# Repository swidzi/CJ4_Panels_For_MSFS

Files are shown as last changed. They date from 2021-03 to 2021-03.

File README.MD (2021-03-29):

# CJ4 Panels

CJ4 Panels are designed to enable an avgeek to build their own Control Panels for [CJ4 Working Tilte Mod](https://github.com/Working-Title-MSFS-Mods/fspackages) for MS Flight Simulator 2020.
Those consist of:

* Eagle files for PCBs (orderable or to be made on a CNC-mill)
* List of electronic components
* STL files for 3d printing
* Inkscape SVG files for laser engraving
* Arduino firmware
* FSUIPC Configuration

Those additionally use certain components from [FlightSimMaker](https://www.thingiverse.com/flightsimmaker/designs) excelent G1000 project - namely [push button switches](https://www.thingiverse.com/thing:4019943) and [Dual Concentric Rotary Encoders](https://www.thingiverse.com/thing:4373531).

## Folder layout

Each panel and component has its own folder. Inside that folder you will find relevant files sorted by type - Eagle, STL etc.
If a certain component requires extra information it will have its own README.MD file.

## Available Panels:

### Primary Flight Display / Display Control Panel

Using a single Arduino/Sparkfun Pro Micro it presents itself to MSFS as a 26 button joystick.

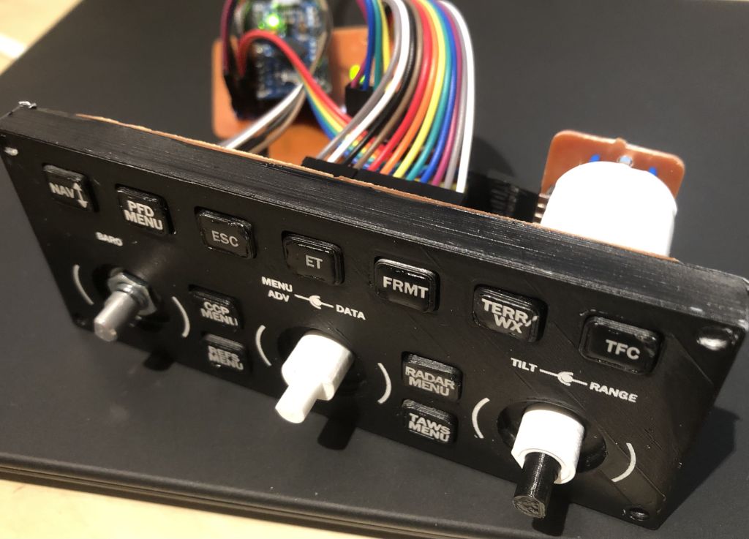
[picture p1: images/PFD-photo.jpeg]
Photo of PFD controller
 <span style="display:block;text-align:center"></span>

## Coming Soon:

### Autopilot / Flight Guindance Panel

Using a single Arduino/Sparkfun Pro Micro it presents itself to MSFS as a 29 button joystick.

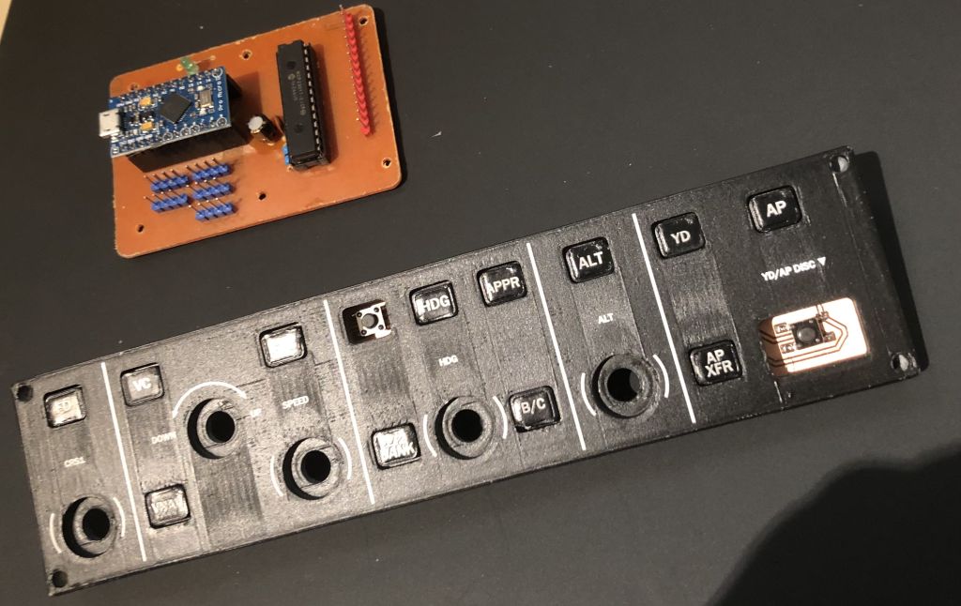
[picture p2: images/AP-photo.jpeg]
Photo of PFD controller
 <span style="display:block;text-align:center"></span>

### Flight Management System (Computer) / Multi-Function Control and Display Unit

Using a single Arudino/Sparkfun Pro Micro and the MMJoy2 interface it presents itself as a 96+ button joystick.

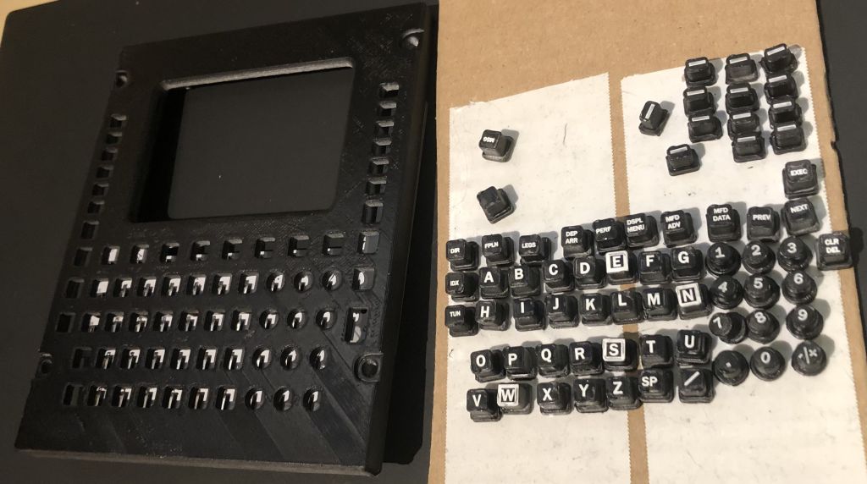
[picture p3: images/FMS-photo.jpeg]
Photo of PFD controller
 <span style="display:block;text-align:center"></span>

### Multi Function Display / Cursor Control Panel

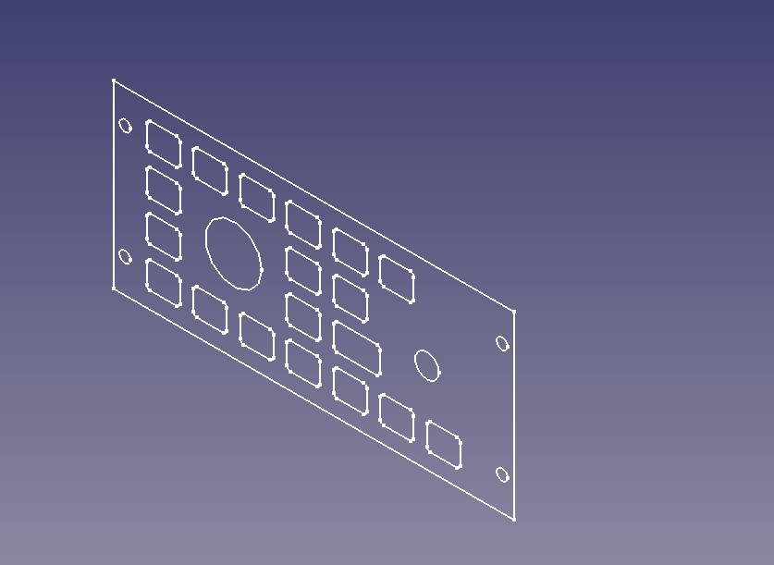
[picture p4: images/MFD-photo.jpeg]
Photo of PFD controller
 <span style="display:block;text-align:center"></span>

## Requirements

* MS Flight Simulator *(I tested it on Steam version)*
* FSUIPC v7 paid version - [link](https://secure.simmarket.com/john-dowson-fsuipc7-for-msfs.phtml)
* MobiFlight WASM module - [link](https://www.mobiflight.com/en/index.html)
* Arduino IDE v1.8.5 or higher - [link](https://www.arduino.cc/)
* Libraries:
	* [Common Bus Encoders](https://github.com/j-bellavance/CommonBusEncoders)
	* Joystick library - available via Manage Libraries in Arduino IDE
	* Adafruit MCP230177 library - available via Manage Libraries in Arduino IDE
* Arduino Pro Micro (based on Atmega32u4) *This is very important! Other AVR chips WILL **NOT** work*

## Building the physical part of the panels

### 3d Printing

Coming soon...

### Laser engraving

Coming soon...

### Making PCBs

Coming soon...

## Installation

#### Installing the software
1. If you have not done so, purchase and install FSUIPC v7
2. Download and install MobiFlight. You do not need to actually be running this software - you just need it's WASM module. Install it in accordance to MobiFlight instructions.
3. Download and install Arduino IDE
* Install required libraries
* If you are using the SparkFun Pro Micro or its clone - Install the proper AVR boards definitions to Arduino Board Manager \([tutorial](https://learn.sparkfun.com/tutorials/installing-arduino-ide/board-add-ons-with-arduino-board-manager)\)

#### Setting up the software:

FSUIPC:
* Copy files from FSUIPC_Configuration folder to your FSUIPC installation folder
* Edit FSUIPC.ini file and modify two lines:
```
[General]
UseProfiles=Files
```
AND
```
[Buttons]
PollInterval=10
```
It is possible that your Arduino Pro Micro joystick will register at a different letter. If that happens you can either:
* Edit the FSUIPC.ini file and change letter assignments in section \[JoyNames\], or
* Edit the Profile files and change letter assignments for each control: For example if you change from Joystick D to F you need to change every occurrence of **PD** to **PF**

#### MS Flight Simulator Setup

At current stage of simulator development no setup is necessary. It is all handled by FSUIPC & MobiFlight combination.

## Usage

Just use like would any joystick controller!

## Contributing

If you find a bug or have a question, feel free to message me on github or to open an Issue.

## Acknowledgments

Many thanks to wonderful people at FlightSimMaker group discord server as well as to all authors who have provided libraries and freeware software available for flightsimmers worldwide

## Questions / Contact

Just drop me an email at swidzi@gmail.com

### License
[GNU GPLv3](https://choosealicense.com/licenses/gpl-3.0/)

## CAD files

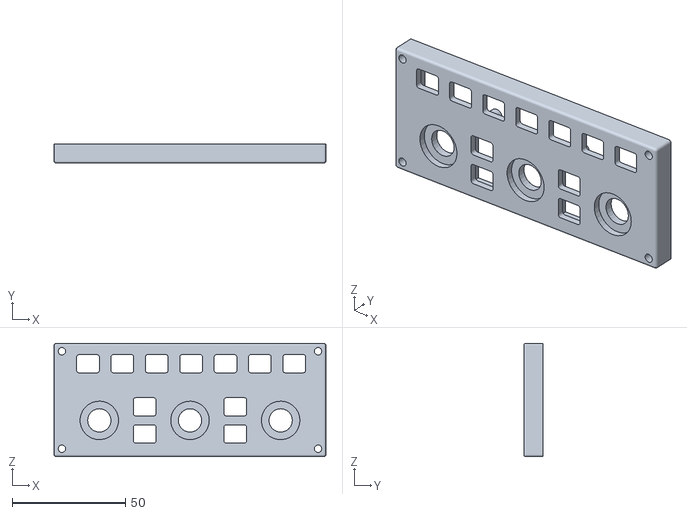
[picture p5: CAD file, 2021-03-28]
PFD/STL/PFD-DCP v2.stl
120.0 x 8.60 x 50.0

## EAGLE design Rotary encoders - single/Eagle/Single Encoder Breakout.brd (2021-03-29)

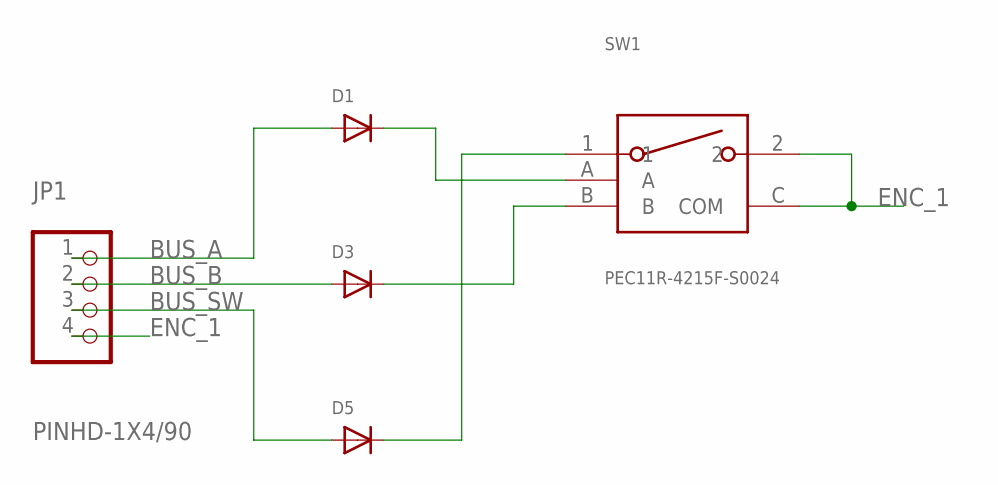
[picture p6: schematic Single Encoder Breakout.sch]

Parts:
D1, D3, D5: DIODESOD-123; SOD-123
JP1: PINHD-1X4/90; 1X04/90
SW1: PEC11R-4215F-S0024

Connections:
BUS_A: D1.A, JP1.1
BUS_B: D3.A, JP1.2
BUS_SW: D5.A, JP1.3
ENC_1: JP1.4, SW1.2, SW1.C (COM)
unnamed: D1.C, SW1.A
unnamed: D3.C, SW1.B
unnamed: D5.C, SW1.1

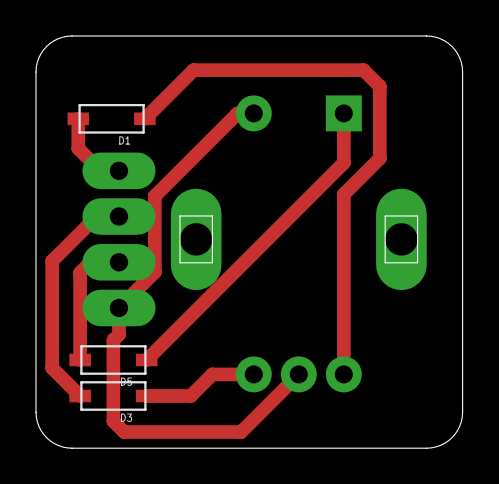
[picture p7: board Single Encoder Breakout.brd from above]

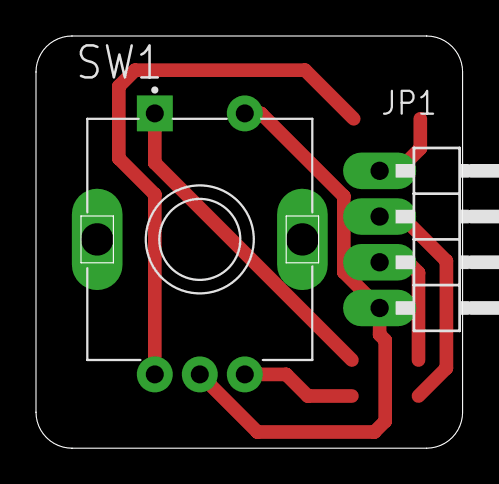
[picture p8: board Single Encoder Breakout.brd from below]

Board: 2 copper layers, 23.7 x 22.9 mm, 5 parts (2 on the bottom side), 7 nets.

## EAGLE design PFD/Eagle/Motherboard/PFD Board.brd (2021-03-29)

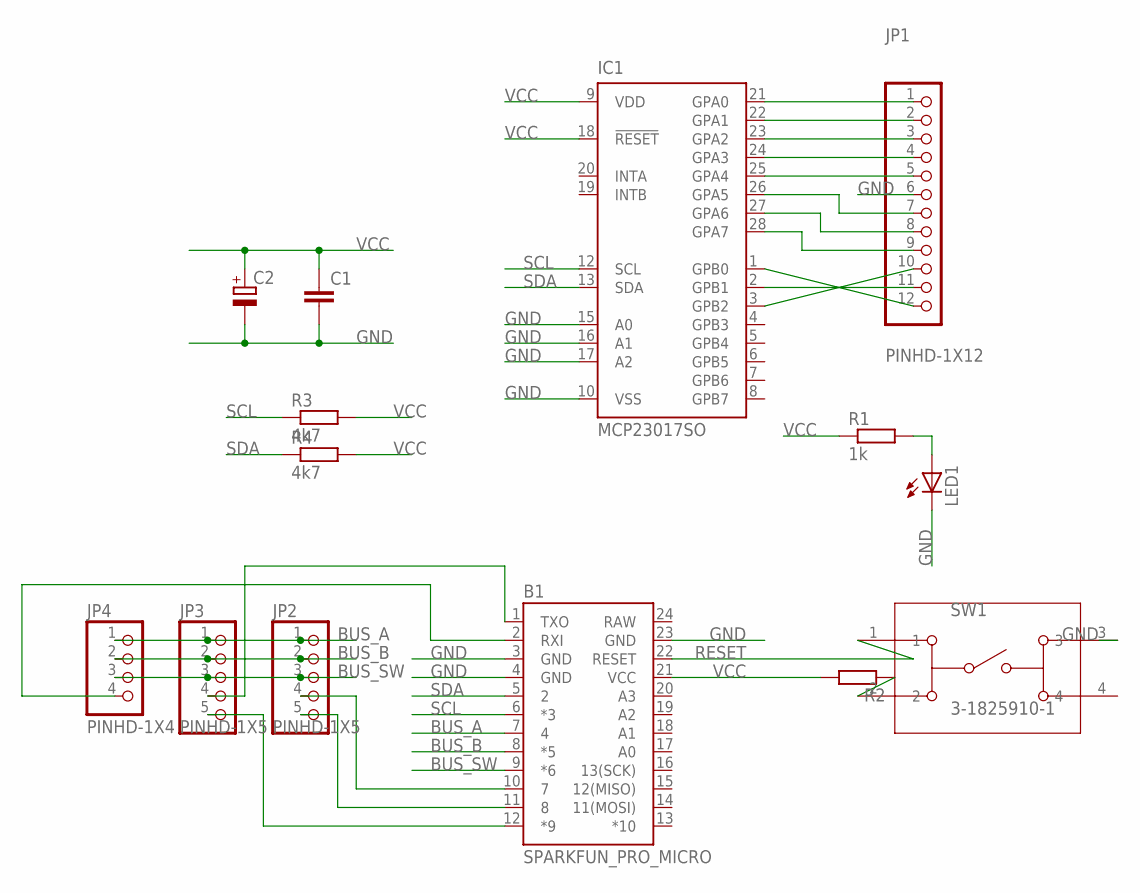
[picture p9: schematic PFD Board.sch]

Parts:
B1: SPARKFUN_PRO_MICRO
C1: C-EU025-025X050; C025-025X050
C2: CPOL-EUE2.5-5; E2,5-5
IC1: MCP23017SO; SO28W
JP1: PINHD-1X12; 1X12
JP2, JP3: PINHD-1X5; 1X05
JP4: PINHD-1X4; 1X04
LED1: LED3MM
R1: 1k; 0207/10
R2: R-EU_0207/10; 0207/10
R3, R4: 4k7; 0207/10
SW1: 3-1825910-1; SW4_1825910-H

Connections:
BUS_A: B1.7 (4), JP2.1, JP3.1, JP4.1
BUS_B: B1.8 (*5), JP2.2, JP3.2, JP4.2
BUS_SW: B1.9 (*6), JP2.3, JP3.3, JP4.3
GND: B1.3 (GND), B1.4 (GND), B1.23 (GND), C1.2, C2.-, IC1.10 (VSS), IC1.15 (A0), IC1.16 (A1), IC1.17 (A2), JP1.6, LED1.K (C), SW1.3
unnamed: B1.10 (7), JP2.4
unnamed: B1.11 (8), JP2.5
unnamed: B1.12 (*9), JP3.5
unnamed: B1.2 (RXI), JP4.4
unnamed: B1.1 (TXO), JP3.4
unnamed: IC1.21 (GPA0), JP1.1
unnamed: IC1.22 (GPA1), JP1.2
unnamed: IC1.23 (GPA2), JP1.3
unnamed: IC1.24 (GPA3), JP1.4
unnamed: IC1.25 (GPA4), JP1.5
unnamed: IC1.1 (GPB0), JP1.12
unnamed: IC1.26 (GPA5), JP1.7
unnamed: IC1.27 (GPA6), JP1.8
unnamed: IC1.28 (GPA7), JP1.9
unnamed: IC1.3 (GPB2), JP1.10
unnamed: IC1.2 (GPB1), JP1.11
unnamed: LED1.A, R1.2
unnamed: R2.1, SW1.2
RAW: B1.24 (RAW)
RESET: B1.22 (RESET), SW1.1
SCL: B1.6 (*3), IC1.12 (SCL), R3.1
SDA: B1.5 (2), IC1.13 (SDA), R4.1
VCC: B1.21 (VCC), C1.1, C2.+, IC1.9 (VDD), IC1.18 (!RESET), R1.1, R2.2, R3.2, R4.2

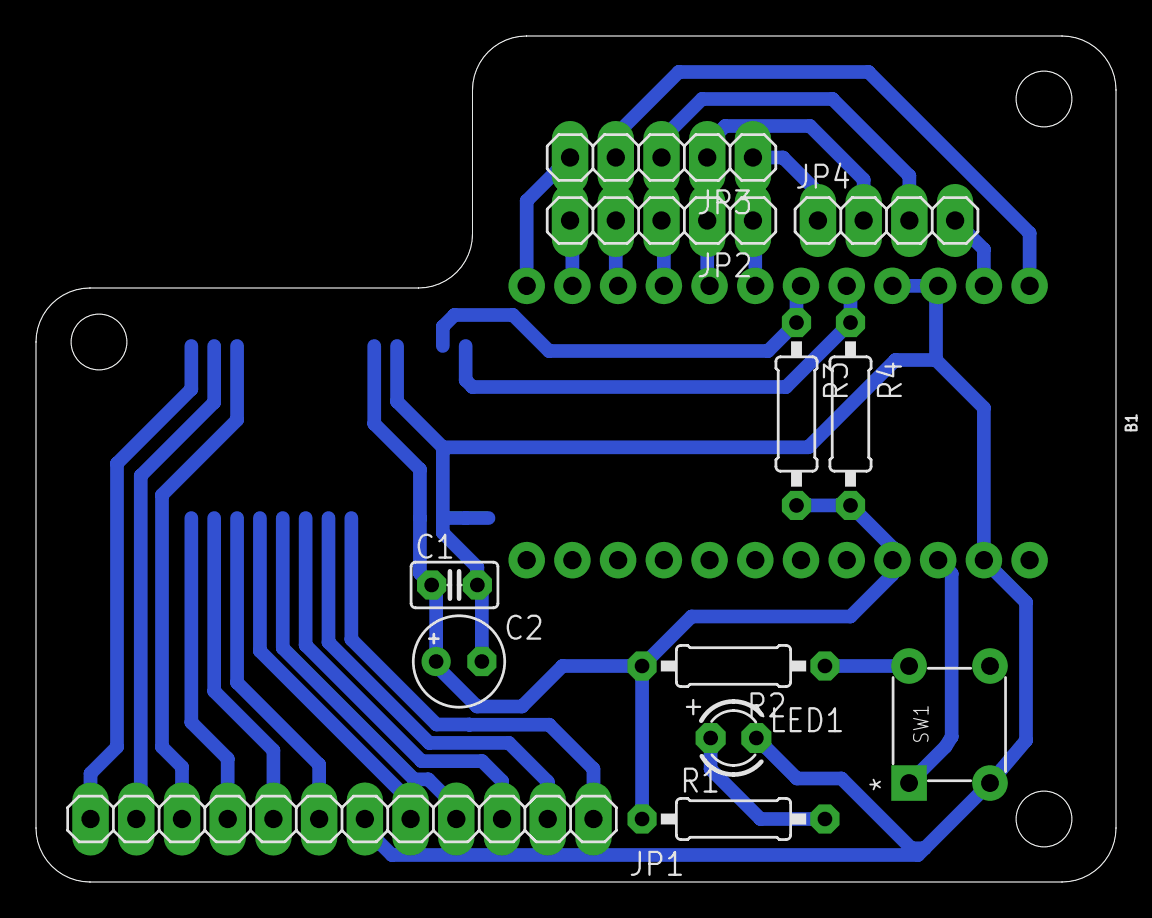
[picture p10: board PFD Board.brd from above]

Board: 2 copper layers, 60.0 x 47.0 mm, 14 parts (1 on the bottom side), 26 nets.

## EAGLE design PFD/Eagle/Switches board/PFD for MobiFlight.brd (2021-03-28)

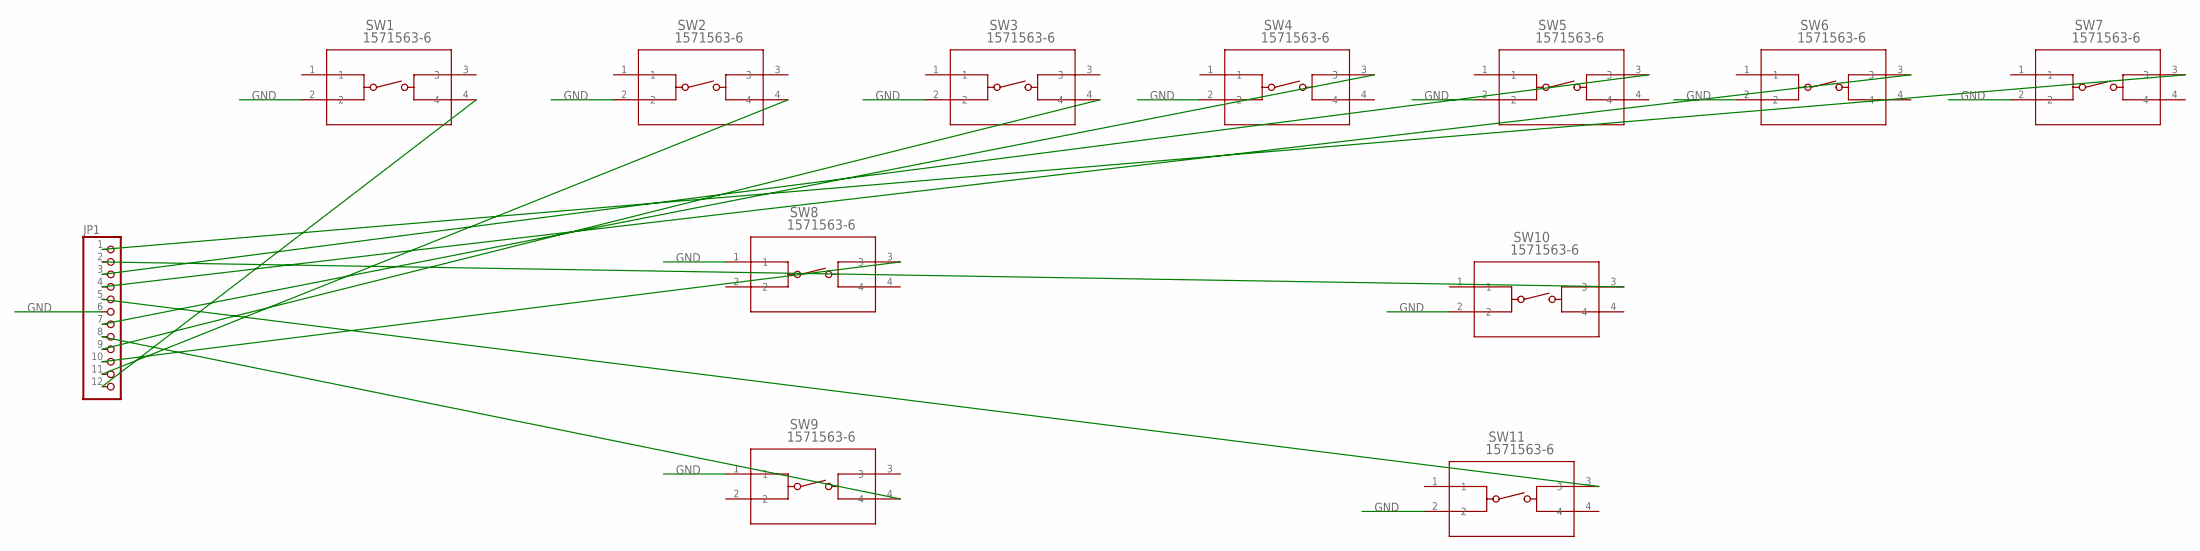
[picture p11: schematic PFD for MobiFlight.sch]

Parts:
JP1: PINHD-1X12; 1X12
SW1, SW2, SW3, SW4, SW5, SW6, SW7, SW8, SW9, SW10, SW11: 1571563-6; SW4_1437565-E

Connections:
GND: JP1.6, SW1.2, SW2.2, SW3.2, SW4.2, SW5.2, SW6.2, SW7.2, SW8.1, SW9.1, SW10.2, SW11.2
unnamed: JP1.7, SW4.3
unnamed: JP1.9, SW3.4
unnamed: JP1.8, SW9.4
unnamed: JP1.10, SW8.3
unnamed: JP1.11, SW2.4
unnamed: JP1.12, SW1.4
unnamed: JP1.3, SW5.3
unnamed: JP1.5, SW11.3
unnamed: JP1.4, SW6.3
unnamed: JP1.1, SW7.3
unnamed: JP1.2, SW10.3

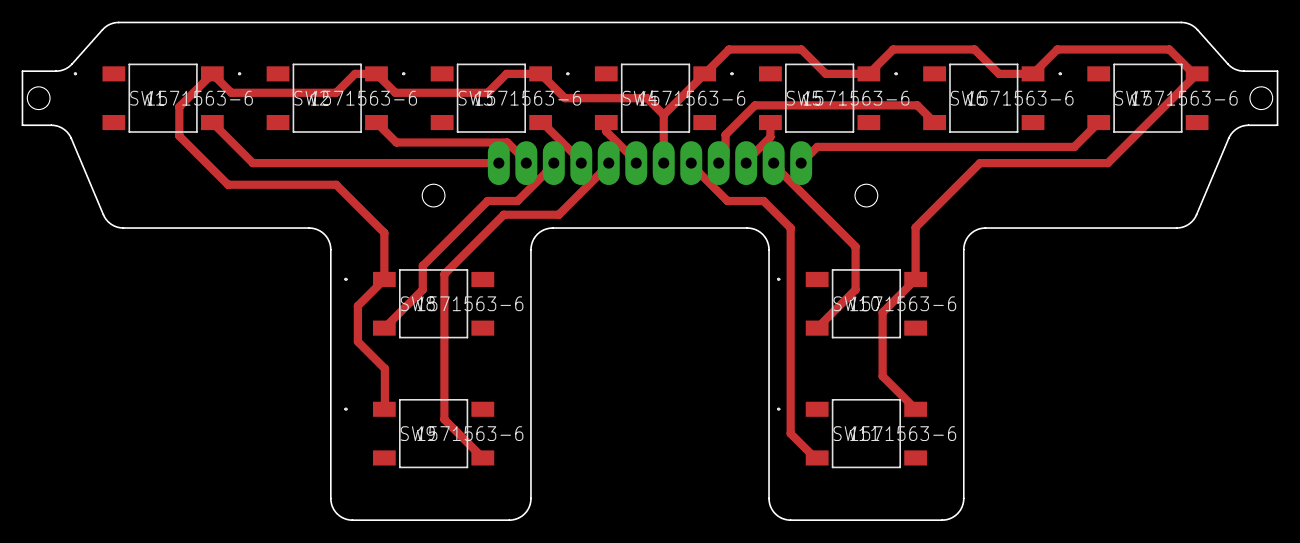
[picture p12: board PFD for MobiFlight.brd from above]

Board: 2 copper layers, 116.0 x 46.0 mm, 12 parts (1 on the bottom side), 12 nets.

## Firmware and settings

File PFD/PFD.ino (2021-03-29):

/*
    CJ4 PFD/DCP Joystick Arduino firmware

    Copyright (c) 2021, Wojciech Swidzinski

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
    You should have received a copy of the GNU General Public License
    along with this program.  If not, see <https://www.gnu.org/licenses/>.
*/

/*
  This code has been made for a PFD/Display Mode Controler for CJ4 mod by Working Title (tested in version 0.11.3).
  It is designed to present a 26 button Joystick. This allows to use software like FSUIPC to map Joystick buttons to MSFS2020 Events.
  I am using the MobiFlight WASM module for the FSUIPC to MSFS interfacing.
  I highly recommend changing the name of the Arduino in boards.txt to something identifying this joystick.
  For example I use "CJ4 PFD_DMC Panel"

  It has been designed to be used with the Arduino Pro Micro or it's clones/derivatives using AtMega32u4 AVR.
*/


#include <CommonBusEncoders.h> //Managing encoders. Common Bus Encoders library version 
#include <Adafruit_MCP23017.h> //Managing switches via I2C Port Expander. Version 1.3.0
#include <Joystick.h> //Managing joystick functionality. Version 2.0.5

//Encoder Bus Pin Assignments
const int busAPin = 4;
const int busBPin = 5;
const int busSwPin = 6;

const int EncoderNumber = 5;
// Encoder Individual Pin Numbers:
const int Encoder_1_Pin_Number = 7;
const int Encoder_2_Pin_Number = 8;
const int Encoder_3_Pin_Number = 9;
const int Encoder_4_Pin_Number = 1;
const int Encoder_5_Pin_Number = 0;

//Initialize Encoders
CommonBusEncoders encoders(busAPin, busBPin, busSwPin, EncoderNumber);

//Initialize MCP23017 Port Expander
Adafruit_MCP23017 mcp; //only one, using default name mcp
const int MCP_Update_Interval = 10; //how often to pool the MCP for new button presses. Default 10 ms.

//Joystick settings
uint8_t buttonCount = 26; //Indicates how many buttons will be available on the joystick.
uint8_t hatSwitchCount = 0; //Indicates how many hat switches will be available on the joystick. Range: 0 - 2
bool includeXAxis = false; //Indicates if the X Axis is available on the joystick.
bool includeYAxis = false; //Indicates if the Y Axis is available on the joystick.
bool includeZAxis = false; //Indicates if the Z Axis (in some situations this is the right X Axis) is available on the joystick.
bool includeRxAxis = false; //Indicates if the X Axis Rotation (in some situations this is the right Y Axis) is available on the joystick.
bool includeRyAxis = false; //Indicates if the Y Axis Rotation is available on the joystick.
bool includeRzAxis = false; //Indicates if the Z Axis Rotation is available on the joystick.
bool includeRudder = false; //Indicates if the Rudder is available on the joystick.
bool includeThrottle = false; //Indicates if the Throttle is available on the joystick.
bool includeAccelerator = false; //Indicates if the Accelerator is available on the joystick.
bool includeBrake = false; //Indicates if the Brake is available on the joystick.
bool includeSteering = false; //Indicates if the Steering is available on the joystick.

// Initialize Joystick
Joystick_ Joy(JOYSTICK_DEFAULT_REPORT_ID,
              JOYSTICK_TYPE_JOYSTICK, buttonCount, hatSwitchCount,
              includeXAxis, includeYAxis, includeZAxis, includeRxAxis, includeRyAxis, includeRzAxis,
              includeRudder, includeThrottle, includeAccelerator, includeBrake, includeSteering);
// Arrays to store Button values
byte OldValues[] = { 0, 0, 0, 0, 0, 0,
                     0, 0, 0, 0, 0
                   };
byte NewValues[] = { 0, 0, 0, 0, 0, 0,
                     0, 0, 0, 0, 0
                   };
// 0 to 10 - physical switches

long LastTimer = 0;
const int TimerDelay = 200;

void setup() {
  // put your setup code here, to run once:
  //start-up the I2C bus
  Wire.setClock(400000); //Make sure it is running in fast mode
  Wire.begin();
  encoders.setDebounce(32); //set debounce - high (to compensate for not so good encoders
  encoders.resetChronoAfter(250); //milliseconds between switching encoders

  //Declare Encoders:
  encoders.addEncoder(1, 4, Encoder_1_Pin_Number, 1, 1100, 1300);
  encoders.addEncoder(2, 4, Encoder_2_Pin_Number, 1, 1400, 1600);
  encoders.addEncoder(3, 4, Encoder_3_Pin_Number, 1, 1700, 1900);
  encoders.addEncoder(4, 4, Encoder_4_Pin_Number, 1, 2000, 2200);
  encoders.addEncoder(5, 4, Encoder_5_Pin_Number, 1, 2300, 2500);

  //Initialize MCP23017
  mcp.begin();
  for (int i = 0; i < 11; i++) { //Iterate through first 10 ports and set them as input with the internal (50-100k) pull up activated
    mcp.pinMode(i, INPUT);
    mcp.pullUp(i, HIGH);
  }
  //Initialize Joystick
  Joy.begin();

}

void BUTTONS() {

  Serial.println("MCP-->");
  for (int i = 0; i < 11 ; i++) //iterate via all pin ports
  {
    NewValues[i] = mcp.digitalRead(i); //Read the pin
    if (NewValues[i] != OldValues[i]) { // On change of pin
      OldValues[i] = NewValues[i]; // Update pin list
      if (NewValues[i] == 1) {
        Joy.releaseButton(i); //on change to high, release button
      }
      if (NewValues[i] == 0) {
        Joy.pressButton(i); //on change to low press button
      }

    }
  }
}

void ENCODERS() {
  //Encoders
  int encoder_code = encoders.readAll();
  if (encoder_code > 0) {
    //Encoder was triggered, so I clear all previous encoders
    for (int i = 11; i < 26; i++) {
      Joy.releaseButton(i); //release all buttons
    }
    // get the button number
    // get the encoder number (encoders give a signal based on their button number):
    int encoder_no = (encoder_code / 100);
    // add the turn number (one direction = button equal to encoder, other direction = button equal to encoder + 1):
    encoder_no = encoder_no + (encoder_code % 100);
    Joy.pressButton(encoder_no); //press triggered button
    LastTimer = millis(); //Make sure that every switch gets at least some milliseconds
  }
  // Make sure to release the button after some time
  if ((LastTimer + TimerDelay) < millis()) {
    for (int i = 11; i < 26; i++) {
      Joy.releaseButton(i);
    }
    LastTimer = millis();
  }

}

void loop() {

  if (millis() % MCP_Update_Interval == 0 ) //Do a comparison every so often
  {
    BUTTONS() ;
  }
  ENCODERS() ;

}

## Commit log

2021-03-28 PFD/DCP Initial release
    [PFD Board.brd, PFD Board.sch, PFD for MobiFlight.brd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]
2021-03-29 Corrected RESET switch design.
    [PFD Board.brd, PFD Board.sch]
2021-03-29 Initial release - Rotary breakout boards
    [Rotary Encoder Breakout.brd, Rotary Encoder Breakout.sch, Single Encoder Breakout.brd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]

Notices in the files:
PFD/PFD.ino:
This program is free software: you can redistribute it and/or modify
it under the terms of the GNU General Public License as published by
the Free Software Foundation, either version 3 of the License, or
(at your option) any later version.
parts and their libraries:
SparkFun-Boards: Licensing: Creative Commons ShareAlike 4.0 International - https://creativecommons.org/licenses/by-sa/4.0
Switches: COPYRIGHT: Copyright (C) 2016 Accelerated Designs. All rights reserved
